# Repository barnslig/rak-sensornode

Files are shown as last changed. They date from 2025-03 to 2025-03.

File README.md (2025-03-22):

# RAK3172 Feather

The RAK3172 feather is a [LoRa](https://www.semtech.com/lora) development board, based on the popular [Adafruit Feather](https://learn.adafruit.com/adafruit-feather/feather-specification) format. It features the [STM32WLE5](https://www.st.com/en/microcontrollers-microprocessors/stm32wle5cc.html) 32-bit ARM Cortex-M4 microcontroller, with 256 Kbytes of Flash memory and 64 Kbytes of SRAM. Being optimized for ultra-low power using the [TPS62840](https://www.ti.com/product/de-de/TPS62840) step-down converter, the board can be used for rapid prototyping of battery-powered IoT sensor nodes.

To ease development, the board is equipped with an on-board [CH343P](https://www.wch-ic.com/products/CH343.html) USB-TTL and a 200mA [TP4054](https://www.umw-ic.com/static/pdf/46c15f53afcf69d99cf4bf3c625c6952.pdf) Li-Po battery charger.

## PCB

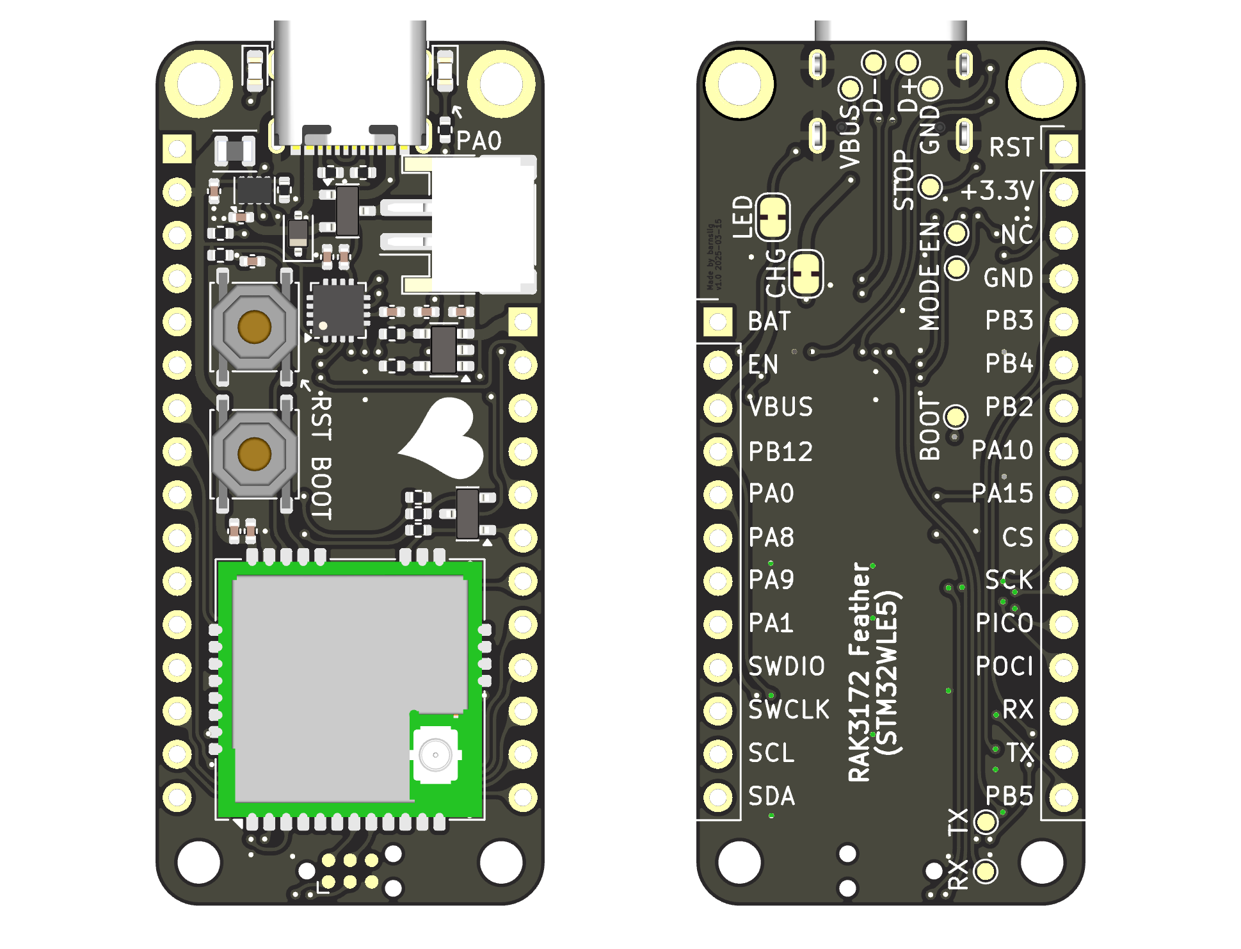
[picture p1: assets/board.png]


## Schematic

Schematic

## Power

External power:

- Board can be powered via USB.
- Connect 3 - 6V DC to VBUS pin or BAT pin.

Battery:

- Connect battery using the JST PH-2 connector or via BAT pin.
- There is an integrated Li-Ion / Li-Po charger, powered via USB / VBUS pin.
- **Cut the CHG jumper on the backisde to disable the charger when using non-rechargeable batterys, e.g. Li-SoCl2 / Li-MnO2!**

Battery Monitoring:

- The voltage on BAT can be measured using the integrated ADC.
- Pull PA8 to GND.
- Measure voltage on PB3 / A0 using the integrated ADC.
- Calculate the battery voltage as follows: `mV * (4700 + 10000) / 10000`.

## User LED

- Integrated LED is connected to PA0 pin.
- Cut the LED jumper on the backside to use the PA0 pin for something else.

## Programming and Firmware

Factory firmware is RUI3 by RAKwireless. See [RAK3172 WisDuo LPWAN Module](https://docs.rakwireless.com/Product-Categories/WisDuo/RAK3172-Module/Overview/).

- Programming can be done via USB serial.
- For programming and debugging, use SWD via the TC2030 connector.

## License

See [LICENSE](./LICENSE).

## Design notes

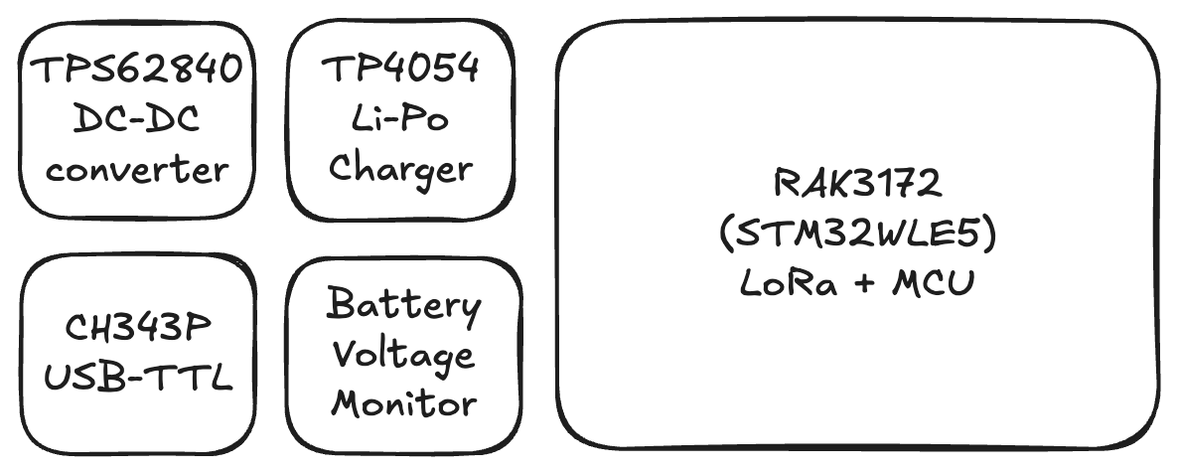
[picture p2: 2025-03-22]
assets/system-blocks.png

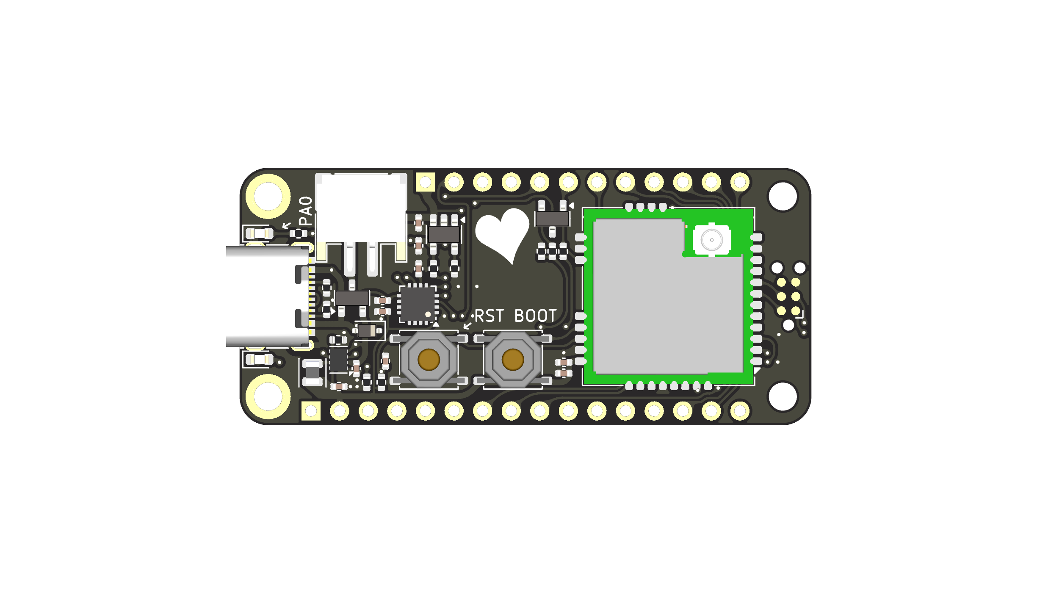
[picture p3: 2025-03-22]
assets/rak-sensornode-front.png

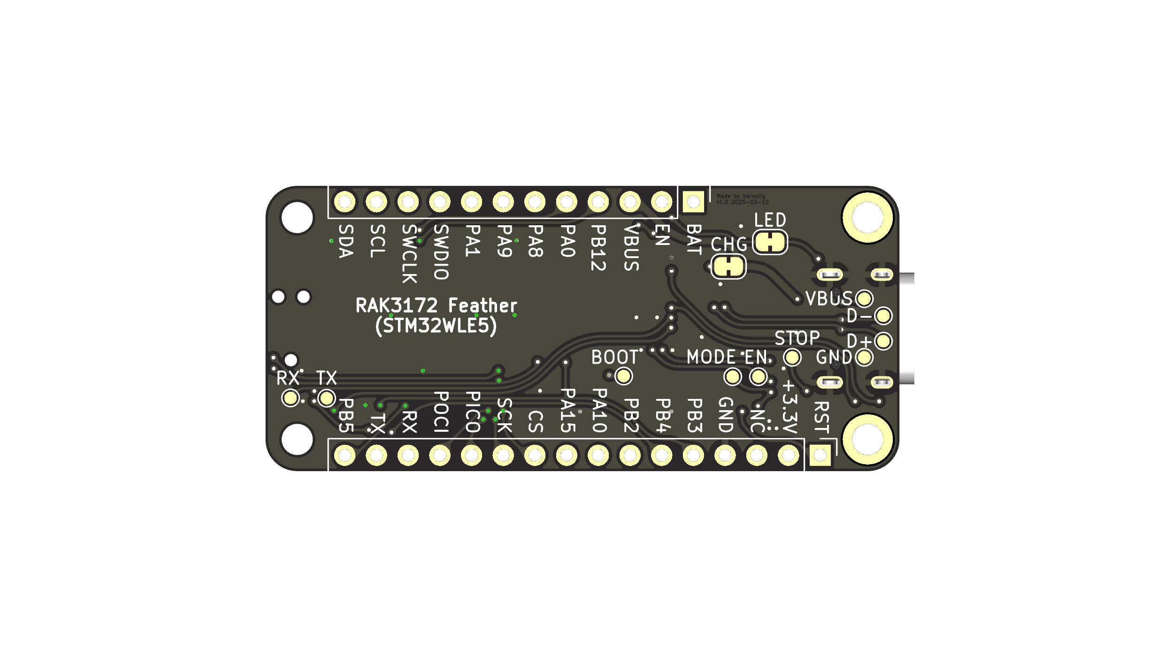
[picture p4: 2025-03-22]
assets/rak-sensornode-back.png

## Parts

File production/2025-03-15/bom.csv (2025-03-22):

Designator | Footprint | Quantity | Value | LCSC Part #
C1, C2, C5 | 0402 | 3 | 100nF
C10, C7 | 0402 | 2 | 4.7uF
C3, C8, C9 | 0402 | 3 | 10uF
C4, C6 | 0402 | 2 | 1uF
D1 | D_SOD-323 | 1 | 1N5819 | C191023
D2 | 0603 | 1 | CHG | C2287
D3 | 0603 | 1 | PA0 | C2286
J1 | USB_C_Receptacle_XKB_U262-16XN-4BVC11 | 1 | USB_C_Receptacle_USB2.0_14P | C2765186
J2 | JST_PH_S2B-PH-SM4-TB_1x02-1MP_P2.00mm_Horizontal | 1 | JST PH-2 | C295747
L1 | L_Murata_DFE201612E | 1 | 2.2uH | C337893
Q1 | SOT-23 | 1 | AO3401A
Q3 | SOT-23 | 1 | AO3401A
R1 | 0402 | 1 | 10K
R10 | 0402 | 1 | 10M
R11 | 0402 | 1 | 1M
R2, R3 | 0402 | 2 | 5.1k
R4 | 0402 | 1 | 10K
R5 | 0402 | 1 | 267k
R6 | 0402 | 1 | 2K
R7, R8 | 0402 | 2 | 1K
R9 | 0402 | 1 | 4.7M
SW1 | TS-1187A-B-A-B | 1 | RST | C318884
SW2 | TS-1187A-B-A-B | 1 | BOOT | C318884
U1 | SOT-23-5 | 1 | TP4054 | C32574
U3 | WCH_QFN-16-1EP_3x3mm_P0.5mm_EP1.8x1.8mm | 1 | CH343P | C2846043
U5 | VSON-8_1.5x2mm_P0.5mm | 1 | TPS62840DLC | C2071859

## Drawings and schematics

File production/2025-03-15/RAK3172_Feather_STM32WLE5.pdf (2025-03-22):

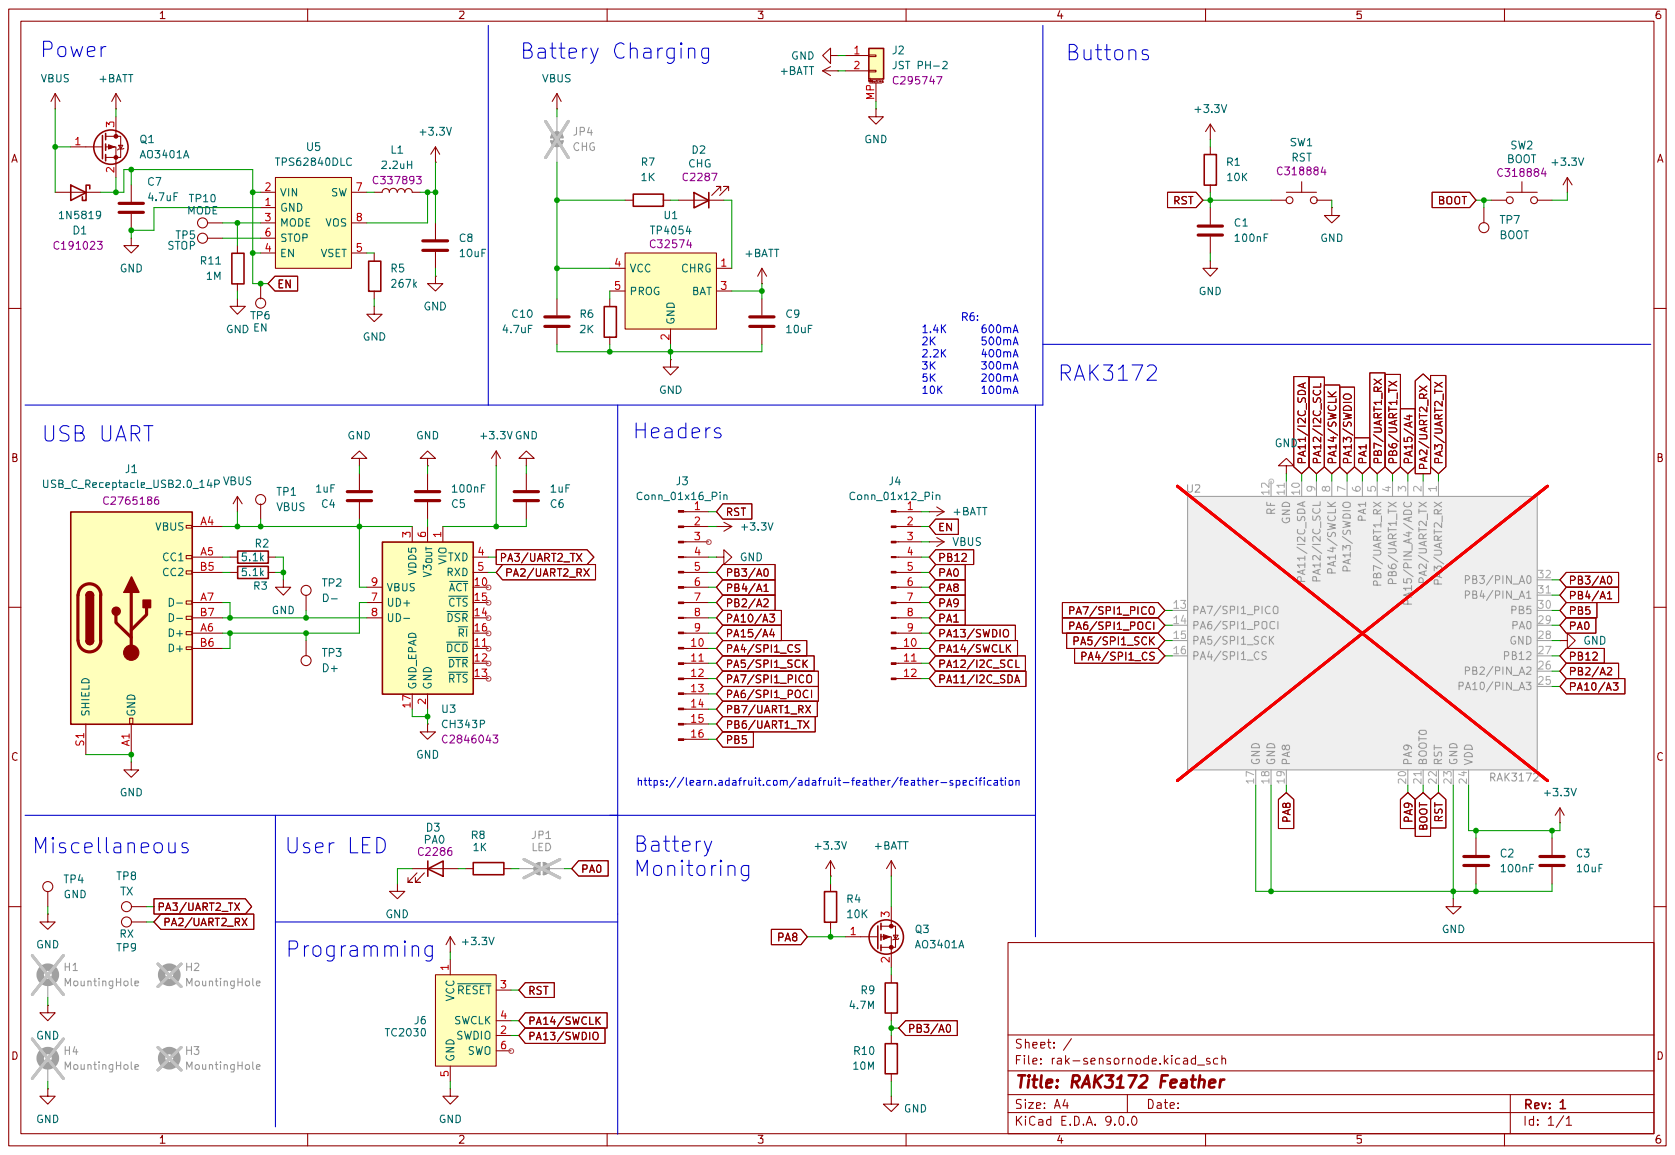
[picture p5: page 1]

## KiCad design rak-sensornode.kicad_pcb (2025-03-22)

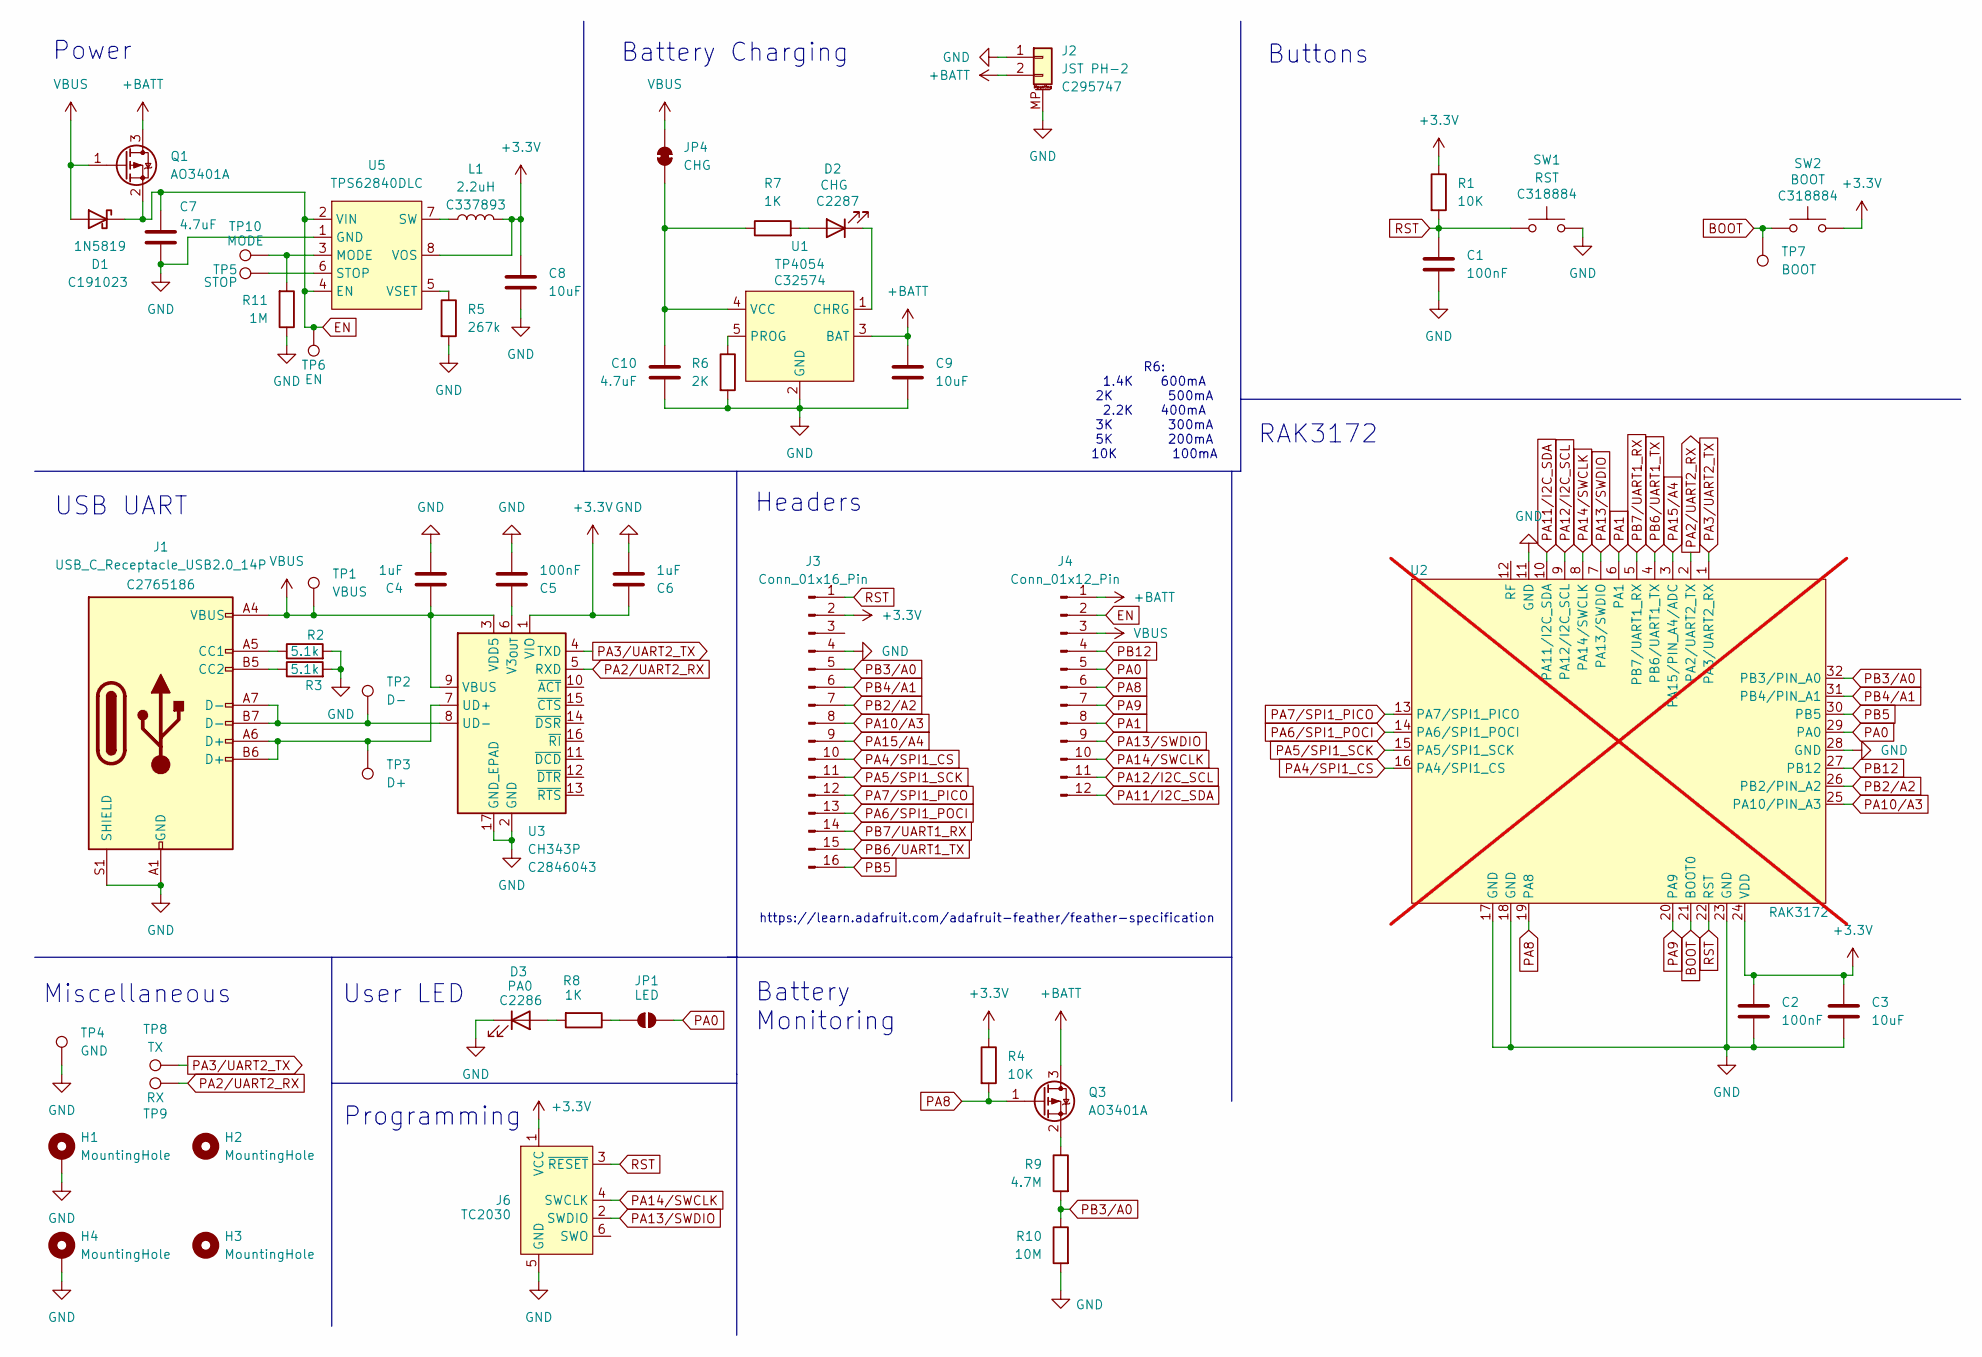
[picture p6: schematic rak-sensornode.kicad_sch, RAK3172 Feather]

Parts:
C1, C2, C5: 100nF; C_0402_1005Metric
C3, C8, C9: 10uF; C_0402_1005Metric
C4, C6: 1uF; C_0402_1005Metric
C7, C10: 4.7uF; C_0402_1005Metric
D1: 1N5819; D_SOD-323; LCSC Part # C191023
D2: CHG; LED_0603_1608Metric; LCSC Part # C2287
D3: PA0; LED_0603_1608Metric; LCSC Part # C2286
H1, H4: MountingHole; MountingHole_2.5mm_Pad_TopBottom
H2, H3: MountingHole; MountingHole_2.5mm
J1: USB_C_Receptacle_USB2.0_14P; USB_C_Receptacle_XKB_U262-16XN-4BVC11; LCSC Part # C2765186
J2: JST PH-2; JST_PH_S2B-PH-SM4-TB_1x02-1MP_P2.00mm_Horizontal; LCSC Part # C295747
J3: Conn_01x16_Pin; PinHeader_1x16_P2.54mm_Vertical
J4: Conn_01x12_Pin; PinHeader_1x12_P2.54mm_Vertical
J6: TC2030; Tag-Connect_TC2030-IDC-NL_2x03_P1.27mm_Vertical
JP1: LED; SolderJumper-2_P1.3mm_Bridged_RoundedPad1.0x1.5mm
JP4: CHG; SolderJumper-2_P1.3mm_Bridged_RoundedPad1.0x1.5mm
L1: 2.2uH; L_Murata_DFE201612E; LCSC Part # C337893
Q1, Q3: AO3401A; SOT-23
R1, R4: 10K; R_0402_1005Metric
R2, R3: 5.1k; R_0402_1005Metric
R5: 267k; R_0402_1005Metric
R6: 2K; R_0402_1005Metric
R7, R8: 1K; R_0402_1005Metric
R9: 4.7M; R_0402_1005Metric
R10: 10M; R_0402_1005Metric
R11: 1M; R_0402_1005Metric
SW1: RST; TS-1187A-B-A-B; LCSC Part # C318884
SW2: BOOT; TS-1187A-B-A-B; LCSC Part # C318884
TP1: VBUS; TestPoint_Pad_D1.0mm
TP2: D-; TestPoint_Pad_D1.0mm
TP3: D+; TestPoint_Pad_D1.0mm
TP4: GND; TestPoint_Pad_D1.0mm
TP5: STOP; TestPoint_Pad_D1.0mm
TP6: EN; TestPoint_Pad_D1.0mm
TP7: BOOT; TestPoint_Pad_D1.0mm
TP8: TX; TestPoint_Pad_D1.0mm
TP9: RX; TestPoint_Pad_D1.0mm
TP10: MODE; TestPoint_Pad_D1.0mm
U1: TP4054; SOT-23-5; LCSC Part # C32574
U2: RAK3172; not fitted
U3: CH343P; WCH_QFN-16-1EP_3x3mm_P0.5mm_EP1.8x1.8mm; LCSC Part # C2846043
U5: TPS62840DLC; VSON-8_1.5x2mm_P0.5mm; LCSC Part C2071859

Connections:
+3.3V: C2.1, C3.1, C6.1, C8.1, J3.2, J6.1 (VCC), L1.2, R1.1, R4.1, SW2.2, U2.24 (VDD), U3.1 (VIO), U5.8 (VOS)
+BATT: C9.1, J2.2, J4.1, Q1.3 (D), Q3.3 (D), U1.3 (BAT)
BOOT: SW2.1, TP7.1, U2.21 (BOOT0)
EN: C7.1, D1.1 (K), J4.2, Q1.2 (S), TP6.1, U5.2 (VIN), U5.4 (EN)
GND: C1.2, C2.2, C3.2, C4.2, C5.2, C6.2, C7.2, C8.2, C9.2, C10.2, D3.1 (K), H1.1, H4.1, J1.A1 (GND), J1.A12 (GND), J1.B1 (GND), J1.B12 (GND), J1.S1 (SHIELD), J2.1, J2.MP (MountPin), J3.4, J6.5 (GND), R2.2, R3.2, R5.2, R6.2, R10.2, R11.1, SW1.2, TP4.1, U1.2 (GND), U2.11 (GND), U2.17 (GND), U2.18 (GND), U2.23 (GND), U2.28 (GND), U3.2 (GND), U3.17 (GND_EPAD), U5.1 (GND)
unnamed: D2.2 (A), R7.2
unnamed: D2.1 (K), U1.1 (CHRG)
unnamed: D3.2 (A), R8.2
unnamed: J1.A5 (CC1), R2.1
unnamed: J1.B5 (CC2), R3.1
unnamed: JP1.1 (A), R8.1
unnamed: C10.1, JP4.1 (A), R7.1, U1.4 (VCC)
unnamed: Q3.2 (S), R9.1
unnamed: R6.1, U1.5 (PROG)
unnamed: J1.A6 (D+), J1.B6 (D+), TP3.1, U3.7 (UD+)
unnamed: J1.A7 (D-), J1.B7 (D-), TP2.1, U3.8 (UD-)
unnamed: C5.1, U3.6 (V3_{OUT})
unnamed: R11.2, TP10.1, U5.3 (MODE)
unnamed: TP5.1, U5.6 (STOP)
unnamed: L1.1, U5.7 (SW)
unnamed: R5.1, U5.5 (VSET)
PA0: J4.5, JP1.2 (B), U2.29 (PA0)
PA1: J4.8, U2.6 (PA1)
PA2/UART2_RX: TP9.1, U2.2 (PA2/UART2_TX), U3.5 (RXD)
PA3/UART2_TX: TP8.1, U2.1 (PA3/UART2_RX), U3.4 (TXD)
PA4/SPI1_CS: J3.10, U2.16 (PA4/SPI1_CS)
PA5/SPI1_SCK: J3.11, U2.15 (PA5/SPI1_SCK)
PA6/SPI1_POCI: J3.13, U2.14 (PA6/SPI1_POCI)
PA7/SPI1_PICO: J3.12, U2.13 (PA7/SPI1_PICO)
PA8: J4.6, Q3.1 (G), R4.2, U2.19 (PA8)
PA9: J4.7, U2.20 (PA9)
PA10/A3: J3.8, U2.25 (PA10/PIN_A3)
PA11/I2C_SDA: J4.12, U2.10 (PA11/I2C_SDA)
PA12/I2C_SCL: J4.11, U2.9 (PA12/I2C_SCL)
PA13/SWDIO: J4.9, J6.2 (SWDIO), U2.7 (PA13/SWDIO)
PA14/SWCLK: J4.10, J6.4 (SWCLK), U2.8 (PA14/SWCLK)
PA15/A4: J3.9, U2.3 (PA15/PIN_A4/ADC)
PB2/A2: J3.7, U2.26 (PB2/PIN_A2)
PB3/A0: J3.5, R9.2, R10.1, U2.32 (PB3/PIN_A0)
PB4/A1: J3.6, U2.31 (PB4/PIN_A1)
PB5: J3.16, U2.30 (PB5)
PB6/UART1_TX: J3.15, U2.4 (PB6/UART1_TX)
PB7/UART1_RX: J3.14, U2.5 (PB7/UART1_RX)
PB12: J4.4, U2.27 (PB12)
RST: C1.1, J3.1, J6.3 (~RESET), R1.2, SW1.1, U2.22 (RST)
VBUS: C4.1, D1.2 (A), J1.A4 (VBUS), J1.A9 (VBUS), J1.B4 (VBUS), J1.B9 (VBUS), J4.3, JP4.2 (B), Q1.1 (G), TP1.1, U3.3 (VDD5), U3.9 (VBUS)

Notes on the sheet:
USB UART
Miscellaneous
RAK3172
Power
Buttons
R6: 1.4K 600mA 2K 500mA 2.2K 400mA 3K 300mA 5K 200mA 10K 100mA
Headers
User LED
https://learn.adafruit.com/adafruit-feather/feather-specification
Battery Charging
Programming
Battery Monitoring

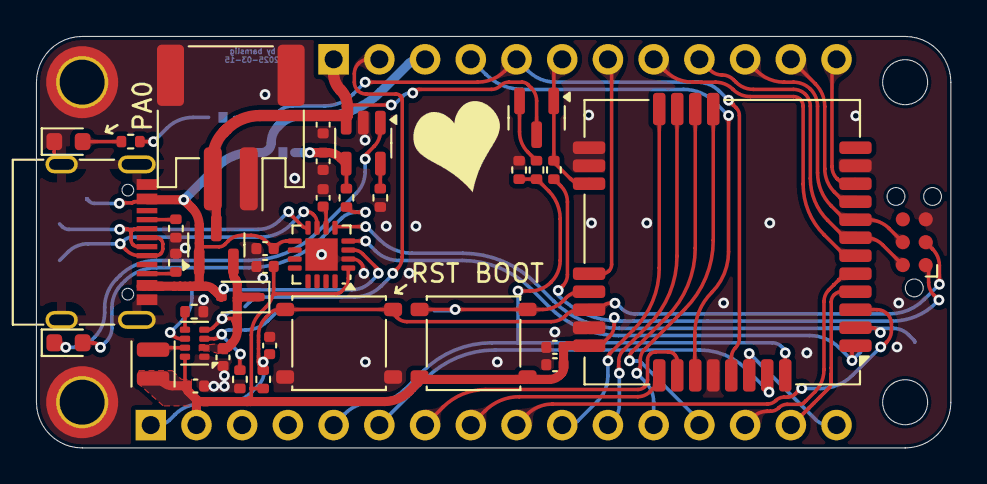
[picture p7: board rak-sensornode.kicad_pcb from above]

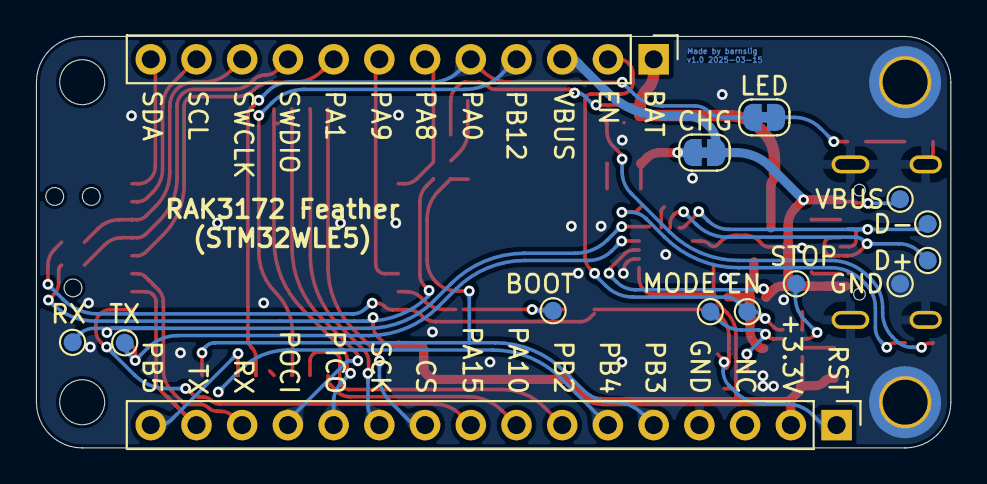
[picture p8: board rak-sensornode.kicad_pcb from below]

Board: 2 copper layers, 50.8 x 22.9 mm, 54 parts (14 on the bottom side), 46 nets.
